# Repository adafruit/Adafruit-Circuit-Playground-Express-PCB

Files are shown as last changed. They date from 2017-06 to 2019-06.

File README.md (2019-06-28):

## Adafruit Circuit Playground Express PCB

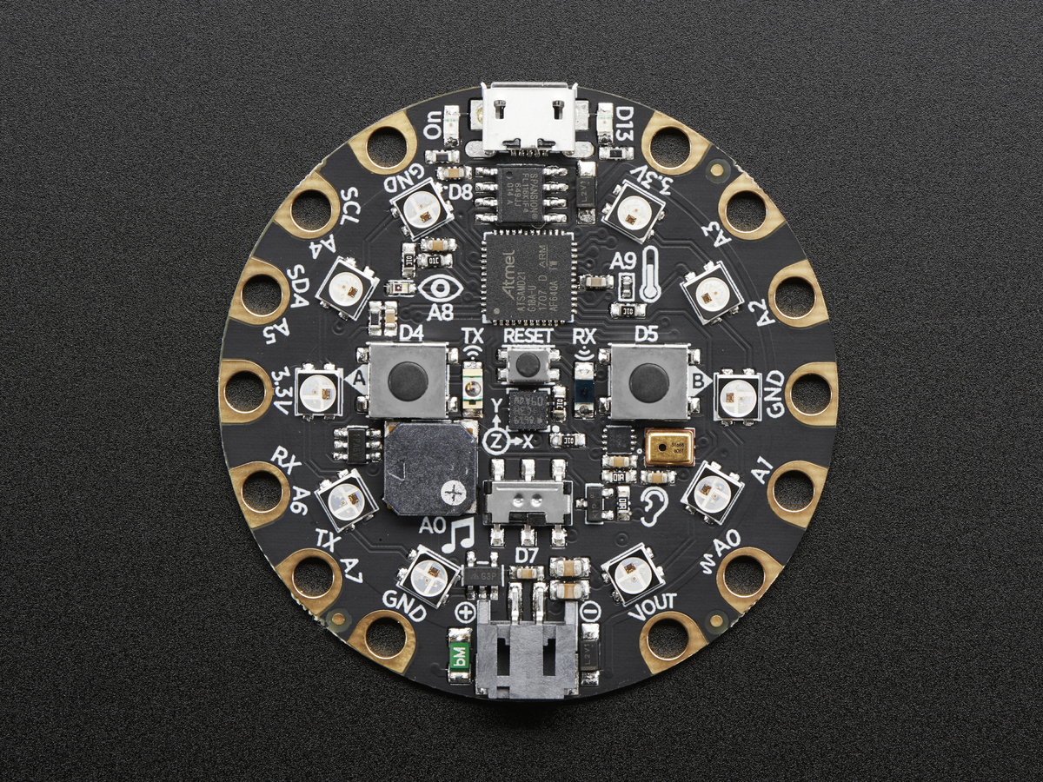
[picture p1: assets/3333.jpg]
<a href="http://www.adafruit.com/products/3333"><br/>
Click here to purchase one from the Adafruit shop</a>

PCB files for the Adafruit Circuit Playground Express. Format is EagleCAD schematic and board layout

For more details, check out the product page at
* http://www.adafruit.com/products/3333

### Description

Circuit Playground Express is the next step towards a perfect introduction to electronics and programming. We've taken the original Circuit Playground Classic and made it even better! Not only did we pack even more sensors in, we also made it even easier to program.

Start your journey with Microsoft MakeCode block-based or Javascript programming. Then, you can use the same board to try CircuitPython, with the Python interpreter running right on the Express. As you progress, you can advance to using Arduino IDE, which has full support of all the hardware down to the low level, so you can make powerful projects.You can even use code.org CS Discoveries to learn all about coding right in your browser!

Check out our detailed guide with a tour of Circuit Playground Express and details on getting started using MakeCode, CircuitPython, code.org CS Discoveries or Arduino!

Because you can program the same board in 4 different ways - the Express has great value and re-usability. From beginners to experts, Circuit Playground Express has something for everyone. If you are looking for our original, Arduino-only Circuit Playground, check out the Circuit Playground Classic.

The board is round and has alligator-clip pads around it so you don't have to solder or sew to make it work. You can power it from USB, a AAA battery pack, or with a Lipoly battery (for advanced users). Circuit Playground Express has built-in USB support. Built in USB means you plug it in to program it and it just shows up, no special cable or adapter required. Just program your code into the board then take it on the go!

### License

Adafruit invests time and resources providing this open source design, please support Adafruit and open-source hardware by purchasing products from [Adafruit](https://www.adafruit.com)!

Designed by Limor Fried/Ladyada for Adafruit Industries.

Creative Commons Attribution/Share-Alike, all text above must be included in any redistribution. See license.txt for additional details.

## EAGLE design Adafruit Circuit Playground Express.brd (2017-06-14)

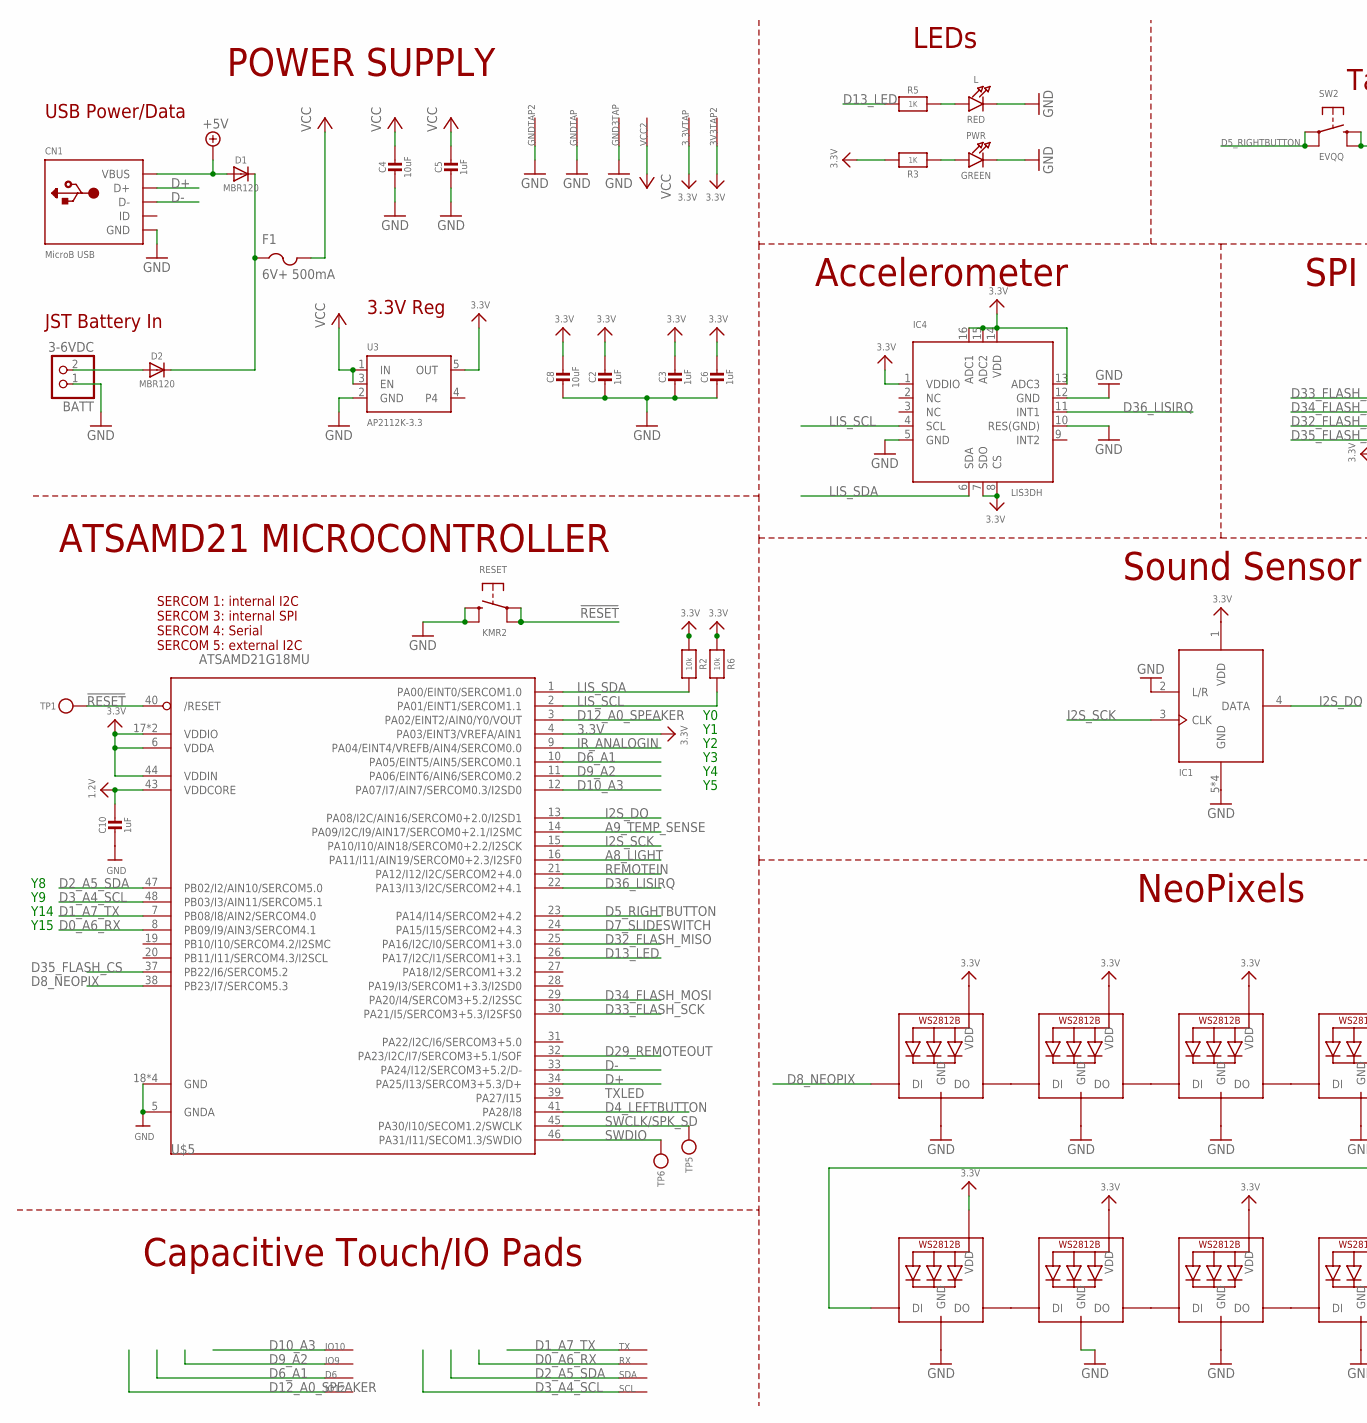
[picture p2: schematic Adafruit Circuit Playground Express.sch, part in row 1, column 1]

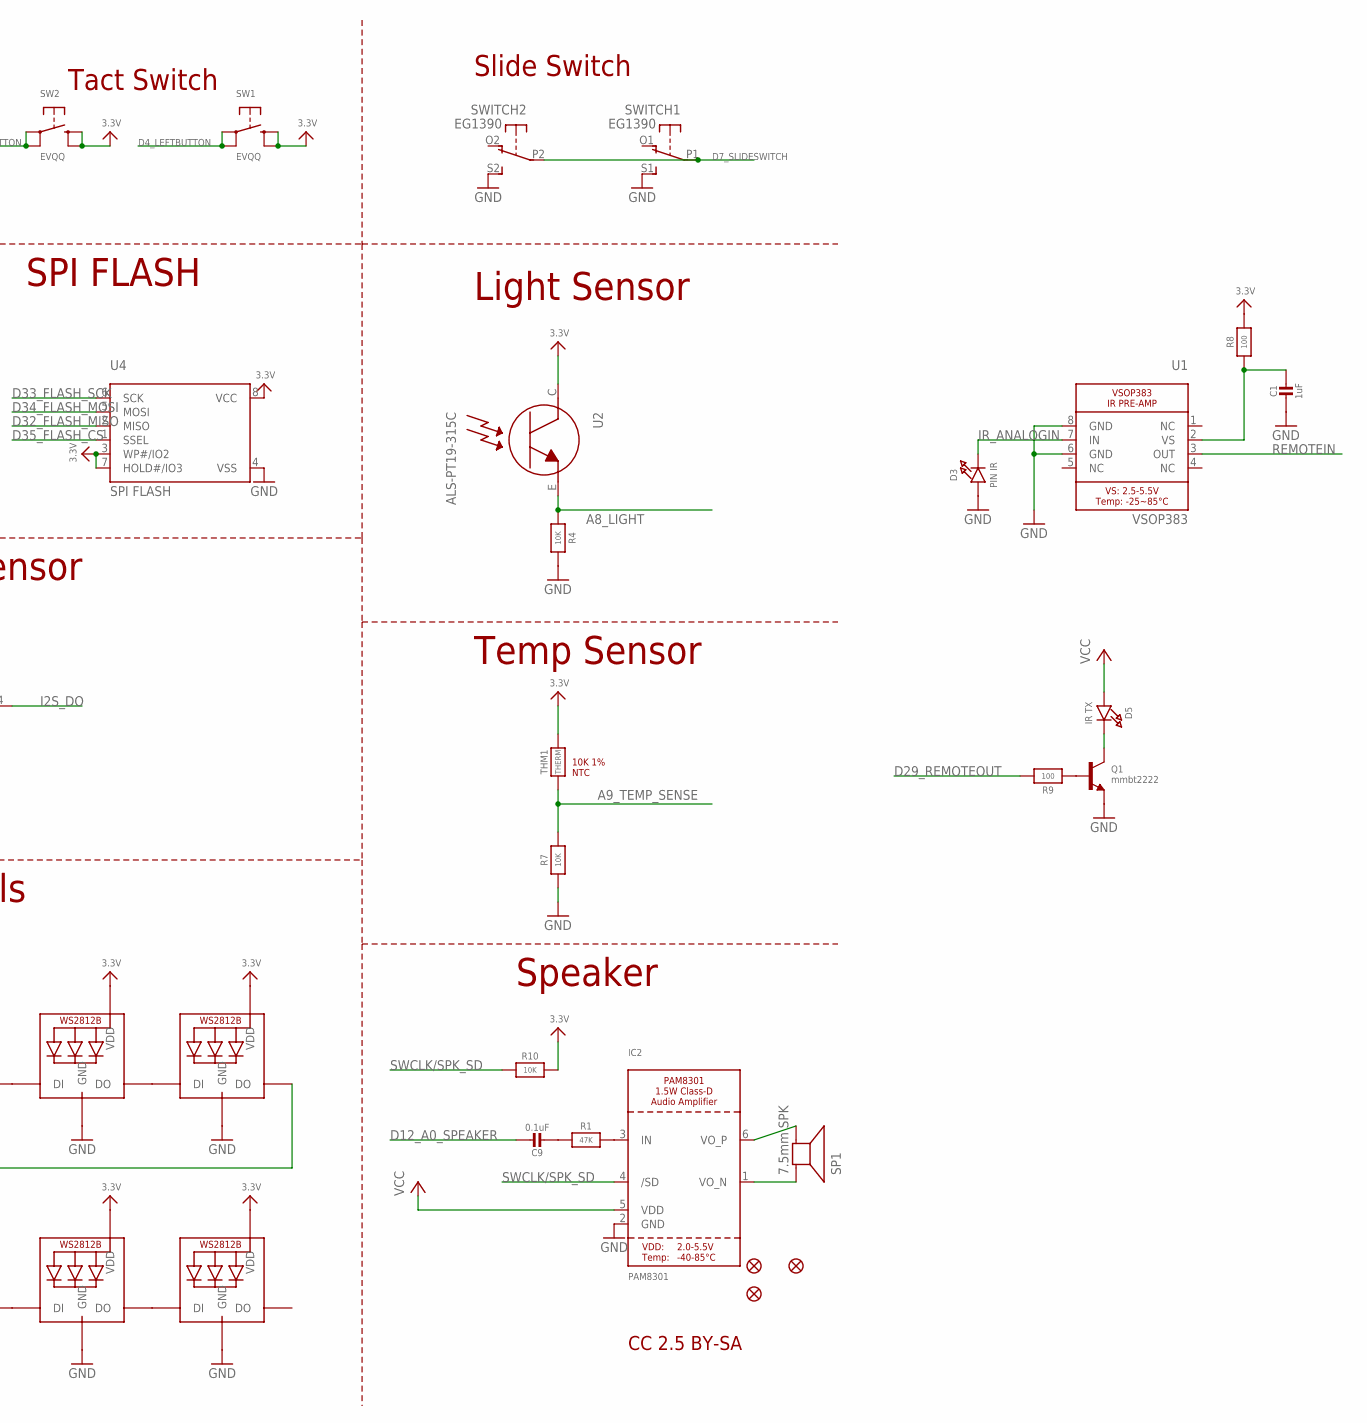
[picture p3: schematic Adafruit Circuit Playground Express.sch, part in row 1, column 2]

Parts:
3.3VTAP, 3V3TAP2: SEWTAP-ALLIGATOR; SEWALLI
BATT: 3-6VDC; JSTPH2
C1, C2, C3, C5, C6, C10: 1uF; 0603-NO
C4, C8: 10uF; 0805-NO
C9: 0.1uF; 0603-NO
CN1: MicroB USB; 4UCONN_20329_V2
D1, D2: MBR120; SOD-123
D3: PIN IR; CHIPLED_1206_NOOUTLINE
D5: IR TX; CHIPLED_1206_NOOUTLINE
D6: SEWTAP-ALLIGATOR; SEWALLI
F1: 6V+ 500mA; R1206
GND3TAP: SEWTAP-ALLIGATOR; SEWALLI
GNDTAP, GNDTAP2: SEWTAP-ALLIGATOR; SEWALLI
IC1: MIC_PDM; SPK0415HM4H
IC2: PAM8301; SOT23-6
IC4: LIS3DH; LGA16_3X3MM
IO9, IO10, IO12: SEWTAP-ALLIGATOR; SEWALLI
L: RED; CHIPLED_0805_NOOUTLINE
LED1, LED2, LED3, LED4, LED5, LED6, LED7, LED8, LED9, LED10: WS2812B3535; LED3535
PWR: GREEN; CHIPLED_0805_NOOUTLINE
Q1: mmbt2222; SOT23-R
R1: 47K; 0603-NO
R2, R6: 10k; 0603-NO
R3, R5: 1K; 0603-NO
R4, R7, R10: 10K; 0603-NO
R8, R9: 100; 0603-NO
RESET: KMR2; BTN_KMR2_4.6X2.8
RX: SEWTAP-ALLIGATOR; SEWALLI
SCL: SEWTAP-ALLIGATOR; SEWALLI
SDA: SEWTAP-ALLIGATOR; SEWALLI
SP1: 7.5mm SPK; BUZZER_SMT_7.5MM
SW1, SW2: EVQQ; EVQ-Q2_SMALLER
SWITCH: EG1390
THM1: THERM; _0402
TP1, TP5, TP6: TESTPOINTROUND1.5MM; TESTPOINT_ROUND_1.5MM
TX: SEWTAP-ALLIGATOR; SEWALLI
U1: VSOP383
U2: ALS-PT19-315C
U3: AP2112K-3.3; SOT23-5
U4: SPI FLASH; SOIC8_150MIL
U$2, U$3, U$6: FIDUCIAL_1MM
U$5: ATSAMD21G18MU; TQFN48_7MM
VCC2: SEWTAP-ALLIGATOR; SEWALLI

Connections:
1.2V: C10.1, U$5.43 (VDDCORE)
3.3V: 3.3VTAP.P$1, 3V3TAP2.P$1, C2.1, C3.1, C6.1, C8.1, IC1.1 (VDD), IC4.1 (VDDIO), IC4.7 (SDO), IC4.8 (CS), IC4.13 (ADC3), IC4.14 (VDD), IC4.15 (ADC2), IC4.16 (ADC1), LED1.2 (VDD), LED2.2 (VDD), LED3.2 (VDD), LED4.2 (VDD), LED5.2 (VDD), LED6.2 (VDD), LED7.2 (VDD), LED8.2 (VDD), LED9.2 (VDD), LED10.2 (VDD), R2.1, R3.2, R6.1, R8.2, R10.2, SW1.B (S), SW1.B' (S1), SW2.B (S), SW2.B' (S1), THM1.2, U2.C, U3.5 (OUT), U4.3 (WP#/IO2), U4.7 (HOLD#/IO3), U4.8 (VCC), U$5.4 (PA03/EINT3/VREFA/AIN1), U$5.6 (VDDA), U$5.17 (VDDIO), U$5.36 (VDDIO), U$5.44 (VDDIN)
!RESET: RESET.A, RESET.A' (P1), TP1.P$1, U$5.40 (/RESET)
+5V: CN1.VBUS, D1.A
A8_LIGHT: R4.2, U2.E, U$5.16 (PA11/I11/AIN19/SERCOM0+2.3/I2SF0)
A9_TEMP_SENSE: R7.2, THM1.1, U$5.14 (PA09/I2C/I9/AIN17/SERCOM0+2.1/I2SMC)
D0_A6_RX: RX.P$1, U$5.8 (PB09/I9/AIN3/SERCOM4.1)
D1_A7_TX: TX.P$1, U$5.7 (PB08/I8/AIN2/SERCOM4.0)
D2_A5_SDA: SDA.P$1, U$5.47 (PB02/I2/AIN10/SERCOM5.0)
D3_A4_SCL: SCL.P$1, U$5.48 (PB03/I3/AIN11/SERCOM5.1)
D4_LEFTBUTTON: SW1.A, SW1.A' (P1), U$5.41 (PA28/I8)
D5_RIGHTBUTTON: SW2.A, SW2.A' (P1), U$5.23 (PA14/I14/SERCOM2+4.2)
D6_A1: D6.P$1, U$5.10 (PA05/EINT5/AIN5/SERCOM0.1)
D7_SLIDESWITCH: SWITCH.P1, SWITCH.P2, U$5.24 (PA15/I15/SERCOM2+4.3)
D8_NEOPIX: LED6.1 (DI), U$5.38 (PB23/I7/SERCOM5.3)
D9_A2: IO9.P$1, U$5.11 (PA06/EINT6/AIN6/SERCOM0.2)
D10_A3: IO10.P$1, U$5.12 (PA07/I7/AIN7/SERCOM0.3/I2SD0)
D12_A0_SPEAKER: C9.1, IO12.P$1, U$5.3 (PA02/EINT2/AIN0/Y0/VOUT)
D13_LED: R5.1, U$5.26 (PA17/I2C/I1/SERCOM1+3.1)
D29_REMOTEOUT: R9.2, U$5.32 (PA23/I2C/I7/SERCOM3+5.1/SOF)
D32_FLASH_MISO: U4.2 (MISO), U$5.25 (PA16/I2C/I0/SERCOM1+3.0)
D33_FLASH_SCK: U4.6 (SCK), U$5.30 (PA21/I5/SERCOM3+5.3/I2SFS0)
D34_FLASH_MOSI: U4.5 (MOSI), U$5.29 (PA20/I4/SERCOM3+5.2/I2SSC)
D35_FLASH_CS: U4.1 (SSEL), U$5.37 (PB22/I6/SERCOM5.2)
D36_LISIRQ: IC4.11 (INT1), U$5.22 (PA13/I13/I2C/SERCOM2+4.1)
D+: CN1.D+, U$5.34 (PA25/I13/SERCOM3+5.3/D+)
D-: CN1.D-, U$5.33 (PA24/I12/SERCOM3+5.2/D-)
GND: BATT.1, C1.2, C2.2, C3.2, C4.2, C5.2, C6.2, C8.2, C10.2, CN1.BASE@1 (GND), CN1.BASE@2 (GND), CN1.GND, CN1.SPRT@1 (GND), CN1.SPRT@2 (GND), CN1.SPRT@3 (GND), CN1.SPRT@4 (GND), D3.A, GND3TAP.P$1, GNDTAP.P$1, GNDTAP2.P$1, IC1.2 (L/R), IC1.5 (GND), IC1.6 (GND), IC1.7 (GND), IC1.8 (GND), IC2.2 (GND), IC4.5 (GND), IC4.10 (RES(GND)), IC4.12 (GND), L.C, LED1.4 (GND), LED2.4 (GND), LED3.4 (GND), LED4.4 (GND), LED5.4 (GND), LED6.4 (GND), LED7.4 (GND), LED8.4 (GND), LED9.4 (GND), LED10.4 (GND), PWR.C, Q1.2 (E), R4.1, R7.1, RESET.B (S), RESET.B' (S1), SWITCH.S1 (S), SWITCH.S2 (S), U1.6 (GND), U1.8 (GND), U3.2 (GND), U4.4 (VSS), U$5.5 (GNDA), U$5.18 (GND), U$5.35 (GND), U$5.42 (GND), U$5.THERMAL (GND)
I2S_DO: IC1.4 (DATA), U$5.13 (PA08/I2C/AIN16/SERCOM0+2.0/I2SD1)
I2S_SCK: IC1.3 (CLK), U$5.15 (PA10/I10/AIN18/SERCOM0+2.2/I2SCK)
IR_ANALOGIN: D3.C, U1.7 (IN), U$5.9 (PA04/EINT4/VREFB/AIN4/SERCOM0.0)
LIS_SCL: IC4.4 (SCL), R6.2, U$5.2 (PA01/EINT1/SERCOM1.1)
LIS_SDA: IC4.6 (SDA), R2.2, U$5.1 (PA00/EINT0/SERCOM1.0)
unnamed: PWR.A, R3.1
unnamed: C1.1, R8.1, U1.2 (VS)
unnamed: D1.C, D2.C, F1.1
unnamed: Q1.1 (B), R9.1
unnamed: C9.2, R1.1
unnamed: BATT.2, D2.A
unnamed: IC2.3 (IN), R1.2
unnamed: IC2.6 (VO_P), SP1.-
unnamed: L.A, R5.2
unnamed: LED1.1 (DI), LED2.3 (DO)
unnamed: LED1.3 (DO), LED3.1 (DI)
unnamed: LED2.1 (DI), LED10.3 (DO)
unnamed: LED6.3 (DO), LED7.1 (DI)
unnamed: IC2.1 (VO_N), SP1.+
unnamed: LED7.3 (DO), LED8.1 (DI)
unnamed: LED8.3 (DO), LED9.1 (DI)
unnamed: LED9.3 (DO), LED10.1 (DI)
unnamed: LED3.3 (DO), LED4.1 (DI)
unnamed: LED4.3 (DO), LED5.1 (DI)
unnamed: D5.C, Q1.3 (C)
REMOTEIN: U1.3 (OUT), U$5.21 (PA12/I12/I2C/SERCOM2+4.0)
SWCLK/SPK_SD: IC2.4 (/SD), R10.1, TP5.P$1, U$5.45 (PA30/I10/SECOM1.2/SWCLK)
SWDIO: TP6.P$1, U$5.46 (PA31/I11/SECOM1.3/SWDIO)
VCC: C4.1, C5.1, D5.A, F1.2, IC2.5 (VDD), U3.1 (IN), U3.3 (EN), VCC2.P$1

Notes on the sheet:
CC 2.5 BY-SA
10K 1% NTC
ATSAMD21 MICROCONTROLLER
USB Power/Data
JST Battery In
3.3V Reg
POWER SUPPLY
NeoPixels
Speaker
Temp Sensor
Light Sensor
Sound Sensor
Slide Switch
Tact Switch
LEDs
Accelerometer
TXLED
SERCOM 1: internal I2C SERCOM 3: internal SPI SERCOM 4: Serial SERCOM 5: external I2C
Y14
Y15
Capacitive Touch/IO Pads
SPI FLASH

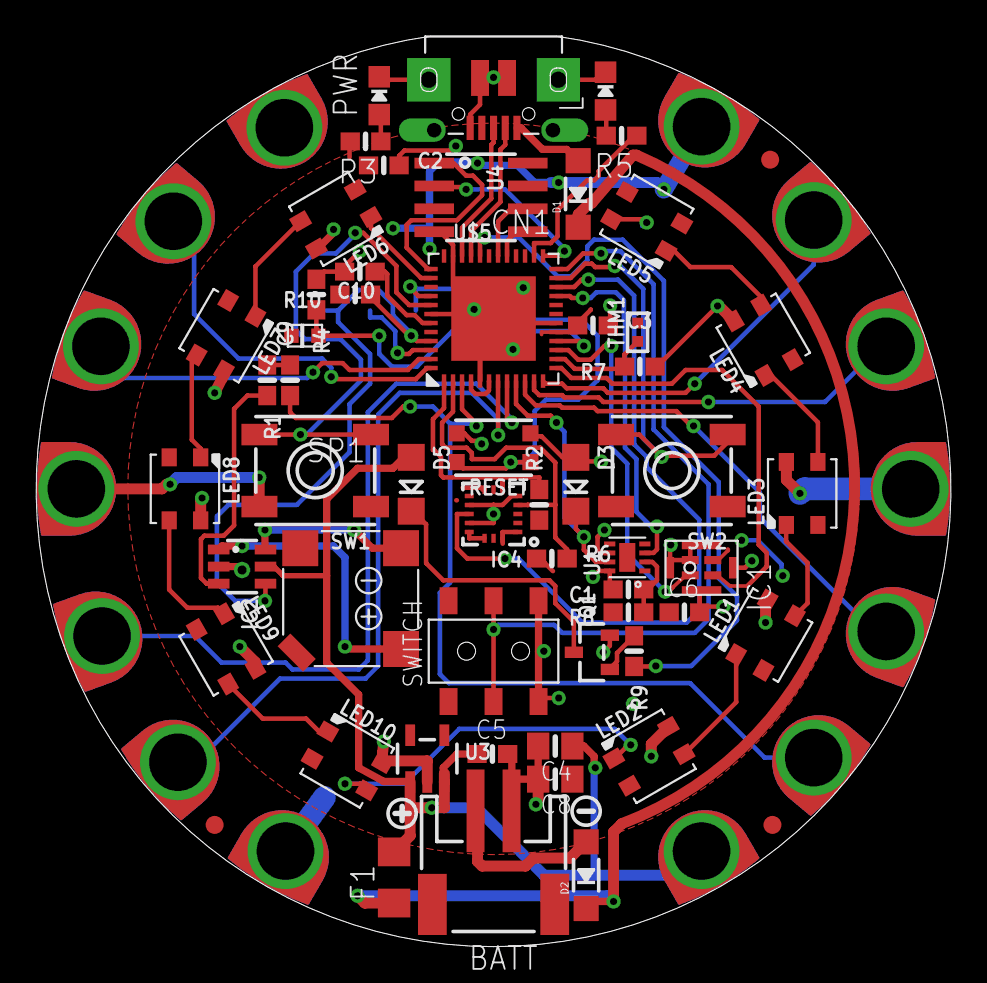
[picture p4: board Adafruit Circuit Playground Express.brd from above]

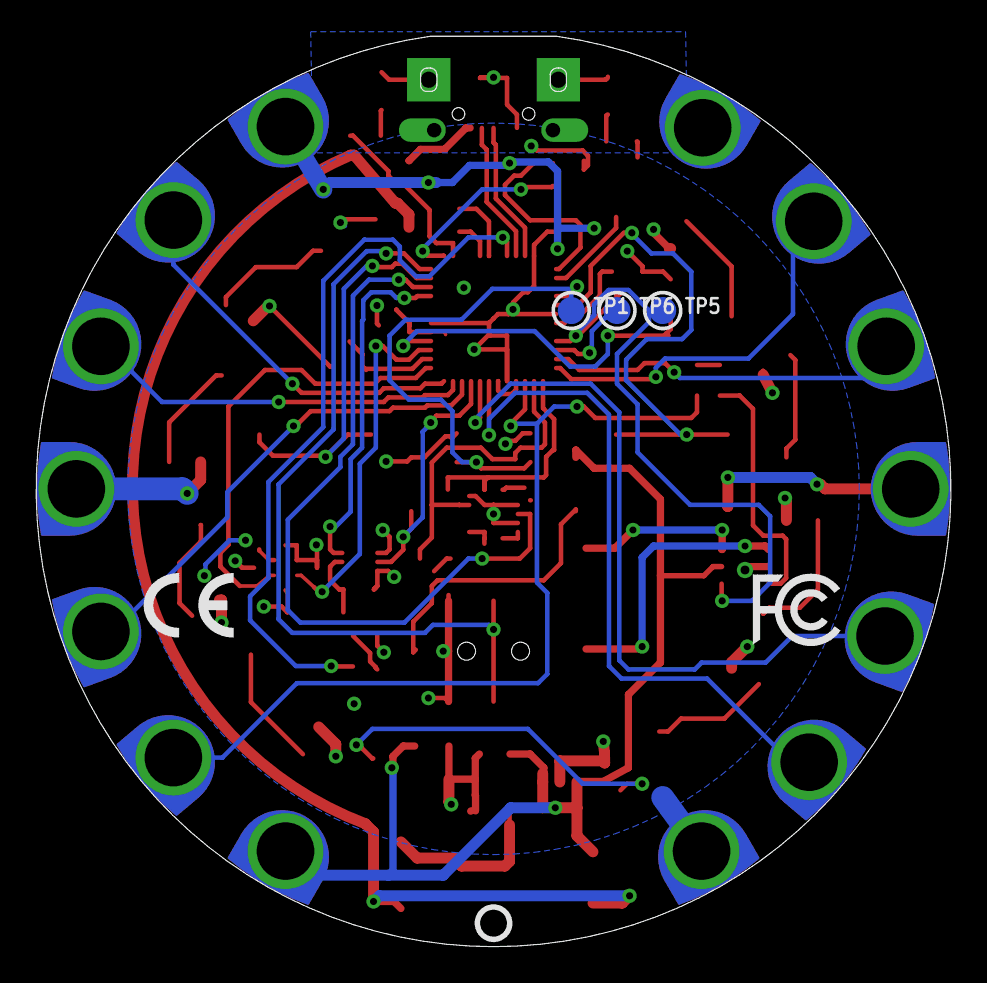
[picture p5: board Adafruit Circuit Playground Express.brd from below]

Board: 2 copper layers, 50.8 x 50.6 mm, 81 parts (8 on the bottom side), 57 nets.

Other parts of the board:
U$1: SYMBOL_MINUS
U$4: FLORAMED
U$7: PCBFEAT-REV-040
U$16: CPLAY_EXPRESS_FRONT_REVG
U$33: SYMBOL_FCC_5MM
U$34: SYMBOL_CE_5MM
U$35: SYMBOL_PLUS
U$46: CPLAY_EXPRESS_BACK_REVD

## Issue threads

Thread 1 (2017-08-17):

PDF Schematic

Kabaju42, 2017-08-17:
Can you upload a PDF of the Circuit Playground Express PCB?

ladyada, 2017-08-17:
please export it using the free eagle viewer!

Closed 2017-08-17.

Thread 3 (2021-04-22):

Speaker seems to be wired backwards

rahji, 2021-04-22:
The negative pin of the PAM8301 audio amplifier goes to the positive pin of the speaker. (net N$15) Is this an oversight or is there a reason why it's wired that way?

ladyada, 2021-04-22:
speakers are not polarized

Closed 2021-04-22.

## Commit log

2017-06-14 woo we're shipping!
    [Adafruit Circuit Playground Express.brd, Adafruit Circuit Playground Express.sch]
2025-09-24 Change battery connector

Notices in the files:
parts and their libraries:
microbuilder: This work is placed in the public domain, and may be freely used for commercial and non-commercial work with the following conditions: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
